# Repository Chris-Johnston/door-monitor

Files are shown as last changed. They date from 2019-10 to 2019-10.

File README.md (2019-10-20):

# door-monitor

An IOT solution to forgetting to lock the door using an ESP32 and a Flask
server. Integrates with Home Assistant and Discord to provide instant
notification of the locked or unlocked state of the door lock and the state
of the door being open.

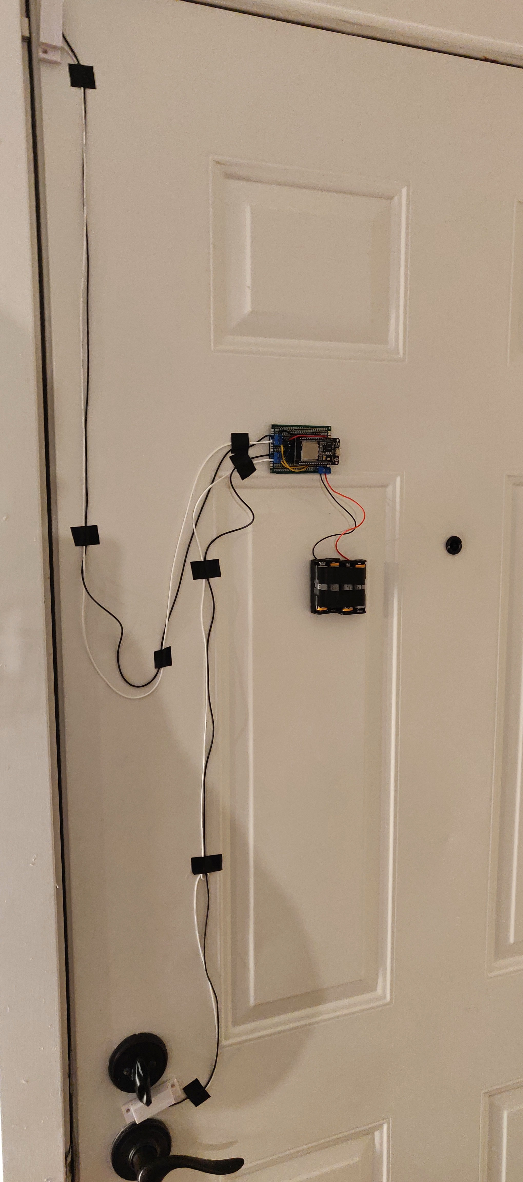
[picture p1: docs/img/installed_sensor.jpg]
image of the installed sensor


Using Home Assistant and Twilio, I can text myself when I leave the
house without locking:

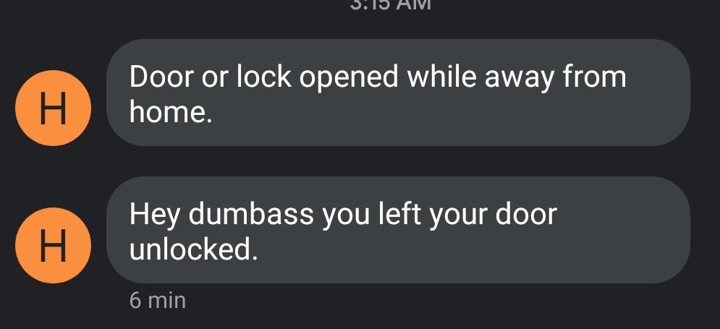
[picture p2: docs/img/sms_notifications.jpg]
image of sms notifications


## Description

This uses an ESP32 dev board connected to two reed switches, one placed on the
door frame, one on the door lock. Hourly, and when the state of the lock or
door sensors are set to "open",
the board will log to the Flask server that collects this data.

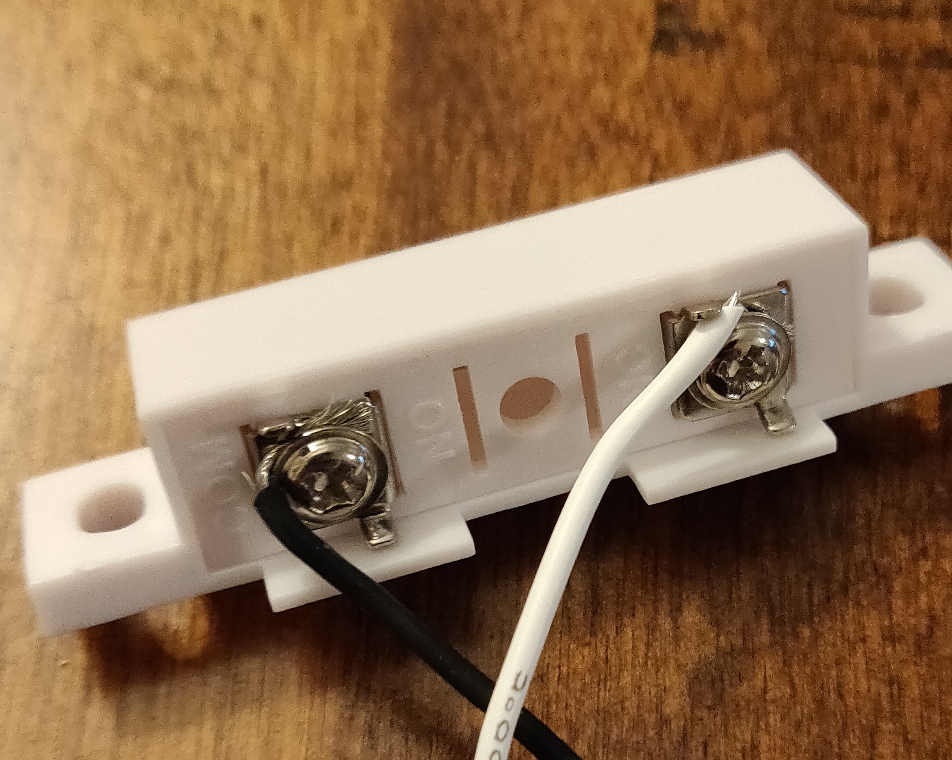
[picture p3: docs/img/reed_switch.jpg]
image of the reed switch


The included magnets to pair with the reed switches I bought were too big
to fit where I needed them, so I used stronger, smaller magnets that
I taped to the lock and the door frame.

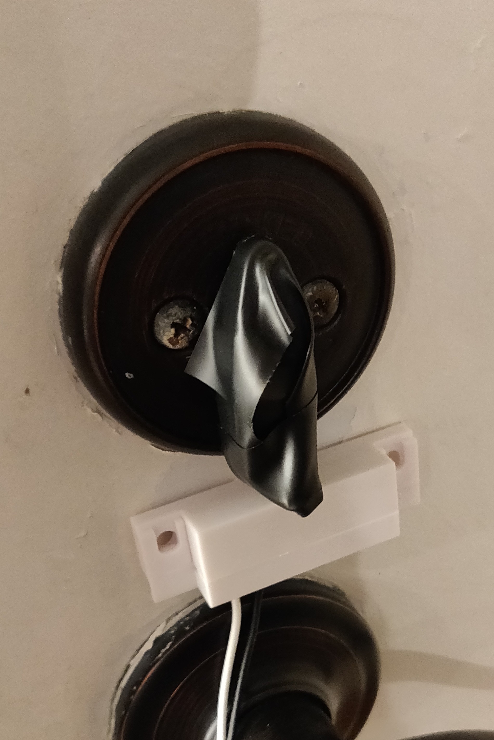
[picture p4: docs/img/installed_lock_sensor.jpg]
image of the installed lock sensor


The data sent from the ESP32 to the Flask server gets forwarded
along to each of the configured webhooks. This can be configured
using the webserver.

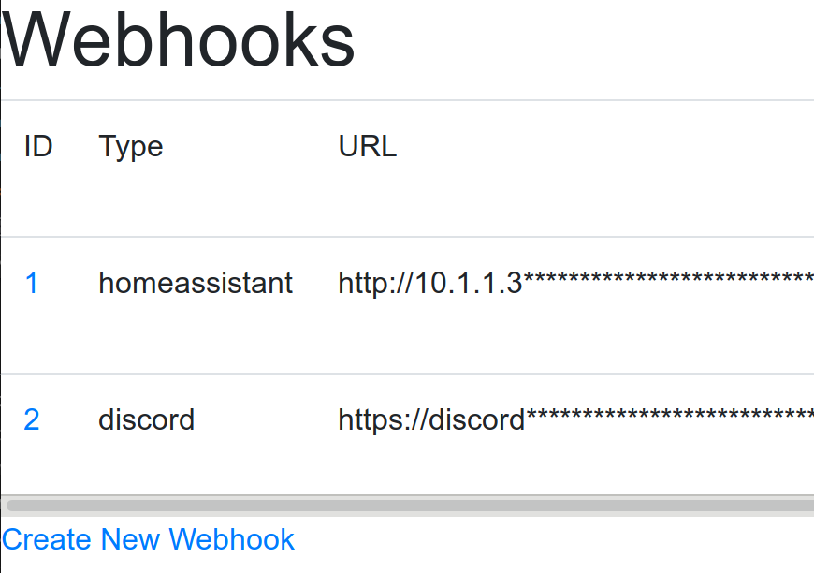
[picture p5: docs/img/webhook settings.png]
image of the configure webhooks page


This integrates with Home Assistant very well.

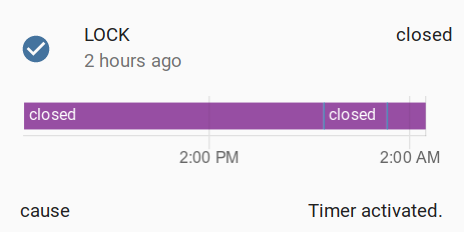
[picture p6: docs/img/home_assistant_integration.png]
image of integration with home assistant


Using the ESP32's "deep sleep" mode and pin interrupts,
the ESP32 is able to run using very little power.

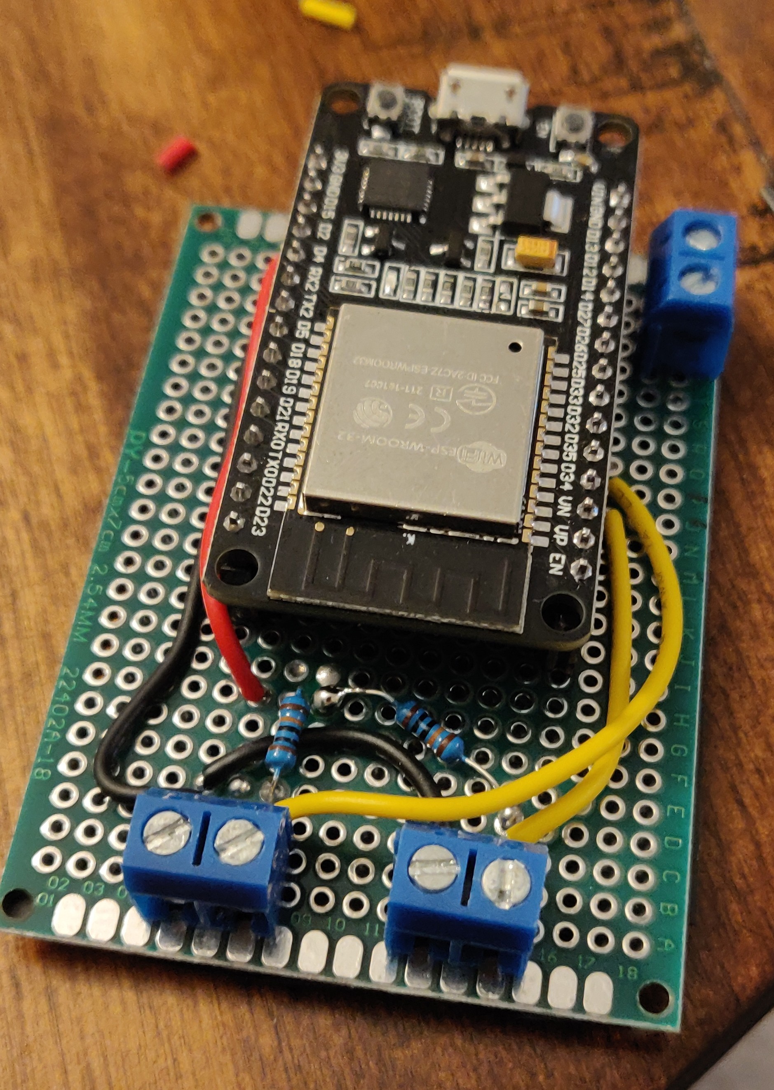
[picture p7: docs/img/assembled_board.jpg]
image of the assembled esp32 board


While the ESP32 is very light on power, the dev board that I'm using
is not.
Even with the power LED removed,
the board was measured to run at 9.8mA in deep sleep mode.
Most of the current
draw is from the USB Controller and voltage regulator.

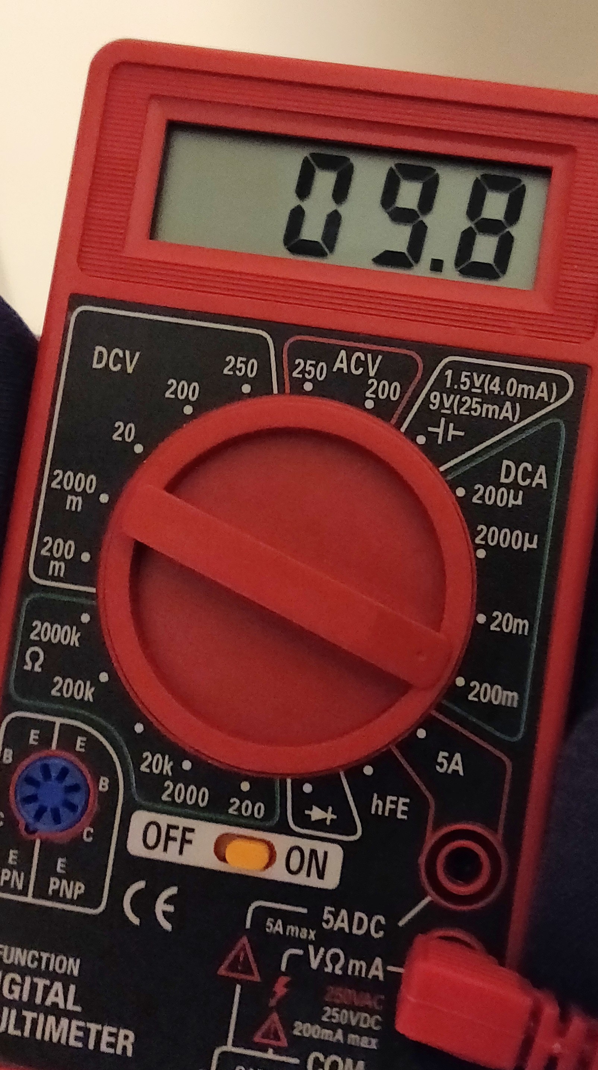
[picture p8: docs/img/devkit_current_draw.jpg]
current draw of esp32 dev board


Running on 4 AA batteries in series (2000-3000 mAh),
the sensor is estimated to run for roughly 200-300 hours.
While this is _okay_, it's not great.
In the future I may change to a more "barebones" solution
that does not include this unnecessary power draw.

## Running the Flask Server

The Flask server runs using Docker. The `uwsgi-nginx-flask`
[image must be built manually if running on a Raspberry Pi.](https://github.com/tiangolo/uwsgi-nginx-flask-docker/issues/67)

When debugging, the server can be started using:

```console
./start_docker_debug.sh
```

When deployed, the server can be started using:

```console
./start_docker.sh
```

## Uploading the sensor-client

The sensor-client is built using Arduino. Ensure that the ESP32 board is
installed.
The Arduino extension for VS Code can upload this sketch.

Modify `config.h` with the wifi settings, URL of the server,
and the pins and names of each of the sensors.

```cpp
#define WIFI_SSID "wifi ssid"
#define WIFI_PSK  "psk"

#define REPORTING_URL "http://10.1.1.2/api/sensor"

// define the sensors
Sensor sensors[] = {
    // pin must be one of 0,2,4,12-15,25-27,32-39
    // those support interrupts while in deep sleep
    // { pin, name of sensor }
    { 32, "LOCK" },
    { 33, "DOOR" },
};

#define NUM_SENSORS 2
```

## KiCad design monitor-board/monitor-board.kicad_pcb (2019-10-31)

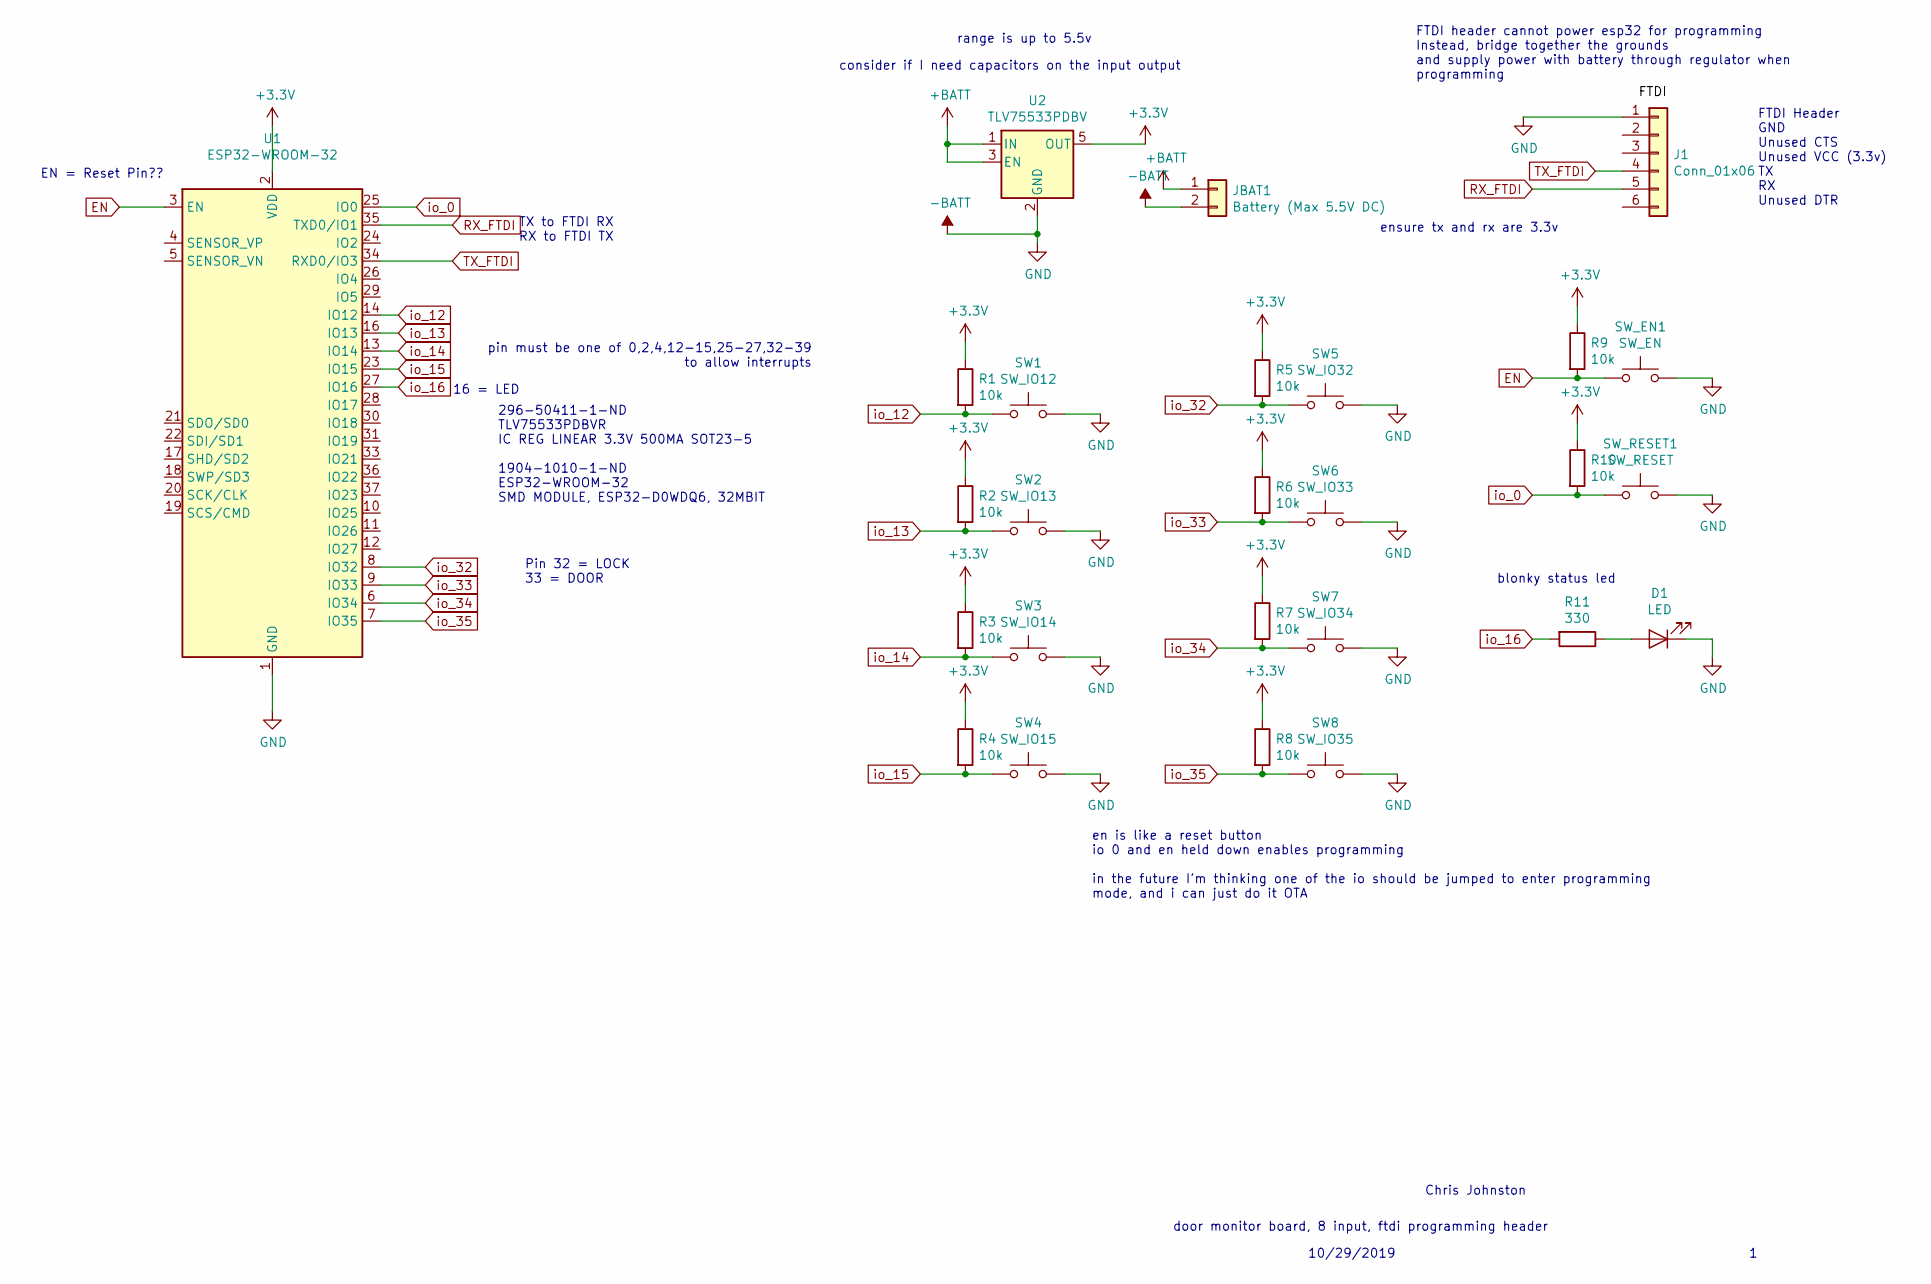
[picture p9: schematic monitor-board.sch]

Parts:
D1: LED; LED_0603_1608Metric_Pad1.05x0.95mm_HandSolder
J1: Conn_01x06; PinSocket_1x06_P2.54mm_Vertical
JBAT1: Battery (Max 5.5V DC); TerminalBlock_Phoenix_PT-1,5-2-5.0-H_1x02_P5.00mm_Horizontal
R1, R2, R3, R4, R5, R6, R7, R8, R9, R10: 10k; R_0603_1608Metric_Pad1.05x0.95mm_HandSolder
R11: 330; R_0603_1608Metric_Pad1.05x0.95mm_HandSolder
SW1: SW_IO12; TerminalBlock_Phoenix_PT-1,5-2-5.0-H_1x02_P5.00mm_Horizontal
SW2: SW_IO13; TerminalBlock_Phoenix_PT-1,5-2-5.0-H_1x02_P5.00mm_Horizontal
SW3: SW_IO14; TerminalBlock_Phoenix_PT-1,5-2-5.0-H_1x02_P5.00mm_Horizontal
SW4: SW_IO15; TerminalBlock_Phoenix_PT-1,5-2-5.0-H_1x02_P5.00mm_Horizontal
SW5: SW_IO32; TerminalBlock_Phoenix_PT-1,5-2-5.0-H_1x02_P5.00mm_Horizontal
SW6: SW_IO33; TerminalBlock_Phoenix_PT-1,5-2-5.0-H_1x02_P5.00mm_Horizontal
SW7: SW_IO34; TerminalBlock_Phoenix_PT-1,5-2-5.0-H_1x02_P5.00mm_Horizontal
SW8: SW_IO35; TerminalBlock_Phoenix_PT-1,5-2-5.0-H_1x02_P5.00mm_Horizontal
SW_EN1: SW_EN; SW_PUSH_6mm
SW_RESET1: SW_RESET; SW_PUSH_6mm
U1: ESP32-WROOM-32
U2: TLV75533PDBV; SOT-23-5

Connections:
+3V3: R1.1, R2.1, R3.1, R4.1, R5.1, R6.1, R7.1, R8.1, R9.1, R10.1, U1.2 (VDD), U2.5 (OUT)
+BATT: JBAT1.1, U2.1 (IN), U2.3 (EN)
-BATT: D1.1 (K), J1.1, JBAT1.2, SW1.2, SW2.2, SW3.2, SW4.2, SW5.2, SW6.2, SW7.2, SW8.2, SW_EN1.2, SW_RESET1.2, U1.1 (GND), U1.15 (GND), U1.38 (GND), U1.39 (GND), U2.2 (GND)
EN: R9.2, SW_EN1.1, U1.3 (EN)
unnamed: D1.2 (A), R11.1
RX_FTDI: J1.5, U1.35 (TXD0/IO1)
TX_FTDI: J1.4, U1.34 (RXD0/IO3)
io_0: R10.2, SW_RESET1.1, U1.25 (IO0)
io_12: R1.2, SW1.1, U1.14 (IO12)
io_13: R2.2, SW2.1, U1.16 (IO13)
io_14: R3.2, SW3.1, U1.13 (IO14)
io_15: R4.2, SW4.1, U1.23 (IO15)
io_16: R11.2, U1.27 (IO16)
io_32: R5.2, SW5.1, U1.8 (IO32)
io_33: R6.2, SW6.1, U1.9 (IO33)
io_34: R7.2, SW7.1, U1.6 (IO34)
io_35: R8.2, SW8.1, U1.7 (IO35)

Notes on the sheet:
FTDI Header GND Unused CTS Unused VCC (3.3v) TX RX Unused DTR
TX to FTDI RX RX to FTDI TX
EN = Reset Pin??
pin must be one of 0,2,4,12-15,25-27,32-39 to allow interrupts
296-50411-1-ND‎ ‎TLV75533PDBVR‎ IC REG LINEAR 3.3V 500MA SOT23-5 1904-1010-1-ND‎ ‎ESP32-WROOM-32‎ SMD MODULE, ESP32-D0WDQ6, 32MBIT
Pin 32 = LOCK 33 = DOOR
consider if I need capacitors on the input output
en is like a reset button io 0 and en held down enables programming in the future I'm thinking one of the io should be jumped to enter programming mode, and i can just do it OTA
blonky status led
door monitor board, 8 input, ftdi programming header
10/29/2019
Chris Johnston
16 = LED
ensure tx and rx are 3.3v
FTDI header cannot power esp32 for programming Instead, bridge together the grounds and supply power with battery through regulator when programming
range is up to 5.5v

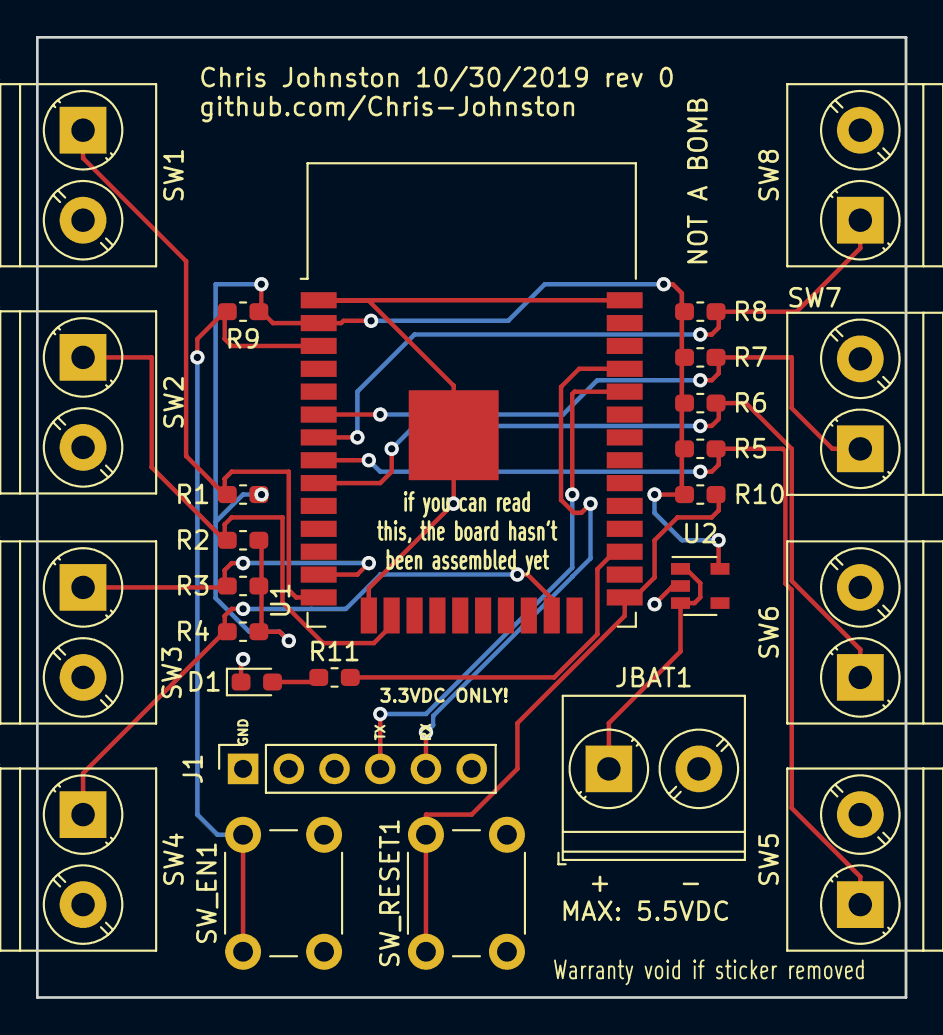
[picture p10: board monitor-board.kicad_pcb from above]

Board: 2 copper layers, 48.3 x 53.3 mm, 26 parts (0 on the bottom side), 17 nets.

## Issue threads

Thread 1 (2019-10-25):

todo: use exponential backoff for "short delay" timer

Chris-Johnston, 2019-10-25:
The "short delay" timer should use exponential backoff, starting at around 30 seconds and going up to the "long delay" timer.

In addition, the 10 second "keep alive" timer should be increased by a bit.

edit: could also consider wiring up inverted logic, so that I can set up interrupts for when a pin resets state. this would remove the need for a short delay timer

Closed 2019-11-06.

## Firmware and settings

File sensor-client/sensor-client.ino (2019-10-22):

#include "Esp.h"
#include "WiFi.h"
#include "HTTPClient.h"
#include "config.h"
#include <ArduinoJson.h>

#define LED_BUILTIN 2

// TODO see if I can report voltage to indicate battery health
// might need to hook up to ADC

// how frequently to report the state, even if the pin
// interrupt has not fired
#define POLL_TIMER (3600000000) // 1 hour

// the amount of time to wait for pins to go LOW
// if they were open
#define SHORT_WAIT_DELAY 10000 // 10 seconds

// how frequently to poll and report the state
// if entering deep sleep because sensors
// are open longer than SHORT_WAIT_DELAY
#define SHORT_POLL_TIMER (300000000) // 5 minutes

RTC_DATA_ATTR int bootCount = 0;

#define CAUSE_SENSOR_CLOSED 100

void blink()
{
    pinMode(LED_BUILTIN, OUTPUT);
    for (int i = 0; i < 2; i++)
    {
        digitalWrite(LED_BUILTIN, HIGH);
        delay(100);
        digitalWrite(LED_BUILTIN, LOW);
        delay(100);
    }
}

void printWakeupCause(int wakeupCause)
{
    Serial.print("Restart due to ");
    switch (wakeupCause)
    {
        case ESP_SLEEP_WAKEUP_EXT1:
            Serial.println("pin state");
            break;
        case ESP_SLEEP_WAKEUP_TIMER:
            Serial.println("timer");
            break;
        default:
            Serial.println("power up");
            break;
    }
}

void printState()
{
    for (auto sensor : sensors)
    {
        Serial.print("Pin ");
        Serial.print(sensor.pin);
        Serial.print(" : ");
        Serial.println(sensor.state);
    }
}

void setupWakeup()
{
    // timer wakeup
    int state = esp_sleep_enable_timer_wakeup(POLL_TIMER);
    if (state != ESP_OK)
    {
        Serial.println("Got error when setting timer wakeup.");
    }

    // pin wakeup
    uint64_t mask = 0;
    for (auto sensor : sensors)
    {
        mask |= ((unsigned long long)1 << sensor.pin);
    }
    
    state = esp_sleep_enable_ext1_wakeup(mask, ESP_EXT1_WAKEUP_ANY_HIGH);
    if (state != ESP_OK)
    {
        Serial.println("Got error when setting ext1 wakeup.");
    }
}

void setupShortWakeup()
{
    // timer wakeup for the short interval
    int state = esp_sleep_enable_timer_wakeup(SHORT_POLL_TIMER);
    if (state != ESP_OK)
    {
        Serial.println("Got error when setting short timer wakeup.");
    }

    // pin wakeup
    // only listen for the pins that are low
    // as this short wakeup period is for the ones that are high
    uint64_t mask = 0;
    for (auto sensor : sensors)
    {
        if (!sensor.state)
            mask |= ((unsigned long long)1 << sensor.pin);
    }
    
    // only use mask if set
    if (mask != 0)
    {
        state = esp_sleep_enable_ext1_wakeup(mask, ESP_EXT1_WAKEUP_ANY_HIGH);
        if (state != ESP_OK)
        {
            Serial.println("Got error when setting ext1 wakeup.");
        }
    }
}

void connectWifi()
{
    WiFi.begin(WIFI_SSID, WIFI_PSK);
    while (WiFi.status() != WL_CONNECTED)
    {
        delay(500);
        Serial.println("Connecting to wifi...");
    }
    // connected
}

void reportStatus(String payload)
{
    HTTPClient client;
    client.begin(REPORTING_URL);
    client.addHeader("Content-Type", "application/json");
    int response = client.POST(payload);
    Serial.print("Got response: ");
    Serial.println(response);
}

bool waitLow()
{
    bool requiredWait = false;
    bool anyHigh = false;

    // check to see if any pins are high
    for (auto sensor : sensors)
    {
        anyHigh |= digitalRead(sensor.pin) == HIGH;
    }

    requiredWait = anyHigh;

    // if pins are high, wait 10 seconds and check again
    if (anyHigh)
    {
        anyHigh = false;
        Serial.println("Waiting 10 seconds for LOW state.");
        delay(SHORT_WAIT_DELAY);

        for (int i = 0; i < NUM_SENSORS; i++)
        {
            sensors[i].state = digitalRead(sensors[i].pin) == HIGH;
            anyHigh |= sensors[i].state;
        }
    }

    // if pins are still high after waiting 5 seconds
    // enter the short deep sleep wakeup interval
    // which will re-scan every 5 minutes
    // and ignore the currently high pins but still handle the low pins
    // once this resets, will resume hour long interval
    if (anyHigh)
    {
        setupShortWakeup();
        Serial.println("Entering short deep sleep.");
        esp_deep_sleep_start();
    }

    return requiredWait;
}

String generatePayload(int wakeupCause)
{
    StaticJsonDocument<400> doc; // TODO - determine a good default for staticjsondocument
    doc["cause"] = wakeupCause;
    JsonArray sensorsArr = doc.createNestedArray("sensors");
    for (auto sensor : sensors)
    {
        auto nestedObj = sensorsArr.createNestedObject();
        nestedObj["name"] = sensor.name;
        nestedObj["state"] = sensor.state;
    }
    String serialized;
    serializeJson(doc, serialized);
    return serialized;
}

void setup()
{
    // read the state of the pins first thing
    for (int i = 0; i < NUM_SENSORS; i++)
    {
        pinMode(sensors[i].pin, INPUT);
        sensors[i].state = digitalRead(sensors[i].pin) == HIGH;
    }

    bootCount++;
    Serial.begin(115200);

    // blink the led on boot
    blink();

    int wakeupCause = esp_sleep_get_wakeup_cause();
    printWakeupCause(wakeupCause);
    printState();

    // generate the json payload
    String serialized = generatePayload(wakeupCause);
    Serial.print("Sending: ");
    Serial.println(serialized);
    connectWifi();

    // report the status of the pins
    reportStatus(serialized);

    // wait for all sensors to return to LOW state
    bool anyHigh = waitLow();

    // if any pins were high and required waiting
    // for less than 10 seconds
    // log again when they
    // are closed
    if (anyHigh)
    {
        Serial.println("Pins were high, logging again now that pins are LOW.");
        // change the wakeup cause for the matching close message
        wakeupCause = CAUSE_SENSOR_CLOSED;

        // log when the sensors go low
        // read state again
        for (int i = 0; i < NUM_SENSORS; i++)
        {
            sensors[i].state = digitalRead(sensors[i].pin) == HIGH;
        }
        Serial.println("Reporting:");
        serialized = generatePayload(wakeupCause);
        Serial.println(serialized);
        reportStatus(serialized);
    }

    setupWakeup();
    Serial.println("Entering deep sleep.");
    esp_deep_sleep_start();
}

void loop()
{
    // unused
}

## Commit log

2019-10-10 add very wip version of sensor client
2019-10-12 shorten sensor open timer to 5s
    [sensor-client.ino]
2019-10-12 report when sensors go low after they are high
2019-10-13 wip landing page
2019-10-22 Add a shorter deep sleep interval for when sensors high
    Adds a shorter deep sleep interval for when sensors are high and stay low for more than 10
    seconds. After 5 minutes, will check the state of the pins once again
    [sensor-client.ino]
2019-10-25 inital commit of monitor-board files
    [monitor-board.kicad_pcb, monitor-board.sch]
2019-10-25 note down parts that I'm using
    [monitor-board.sch]
2019-10-30 finish first version of monitor board schematic
    [monitor-board.sch]
2019-10-30 setup footprints
    [monitor-board.kicad_pcb, monitor-board.sch]
2019-10-30 initial layout of footprints
    [monitor-board.kicad_pcb, monitor-board.sch]
2019-10-30 fix footprints of led and switches
    [monitor-board.kicad_pcb, monitor-board.sch]
2019-10-30 add traces
    [monitor-board.kicad_pcb]
2019-10-30 finish routing the PCB
    [monitor-board.kicad_pcb]
2019-10-30 leave a TODO
    [monitor-board.kicad_pcb]
2019-10-31 remove todo text, part matched footprint
    [monitor-board.kicad_pcb]
2019-10-31 Update footprints of resistors and led to go with cheap parts
    [monitor-board.kicad_pcb, monitor-board.sch]
2019-10-31 dont add crob image
    [monitor-board.kicad_pcb]
2019-10-31 update silkscreen
    [monitor-board.kicad_pcb]
2019-10-31 update from refill
    [monitor-board.kicad_pcb]
2019-10-31 trim edges of board
    [monitor-board.kicad_pcb]
